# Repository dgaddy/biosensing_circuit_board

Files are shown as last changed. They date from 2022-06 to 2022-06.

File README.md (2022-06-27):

These designs are for a low-cost biosensing board for measuring signals such as EMG, EEG, or ECG.

The board is designed to plug into an Adafruit Feather M4 Express and send the collected signals back to a computer over USB.

**Disclaimer:** Connecting electrical circuitry to your body can be dangerous.  I do not make any guarantees to the safety of this design.  Before building, you should conduct your own analysis of safety.

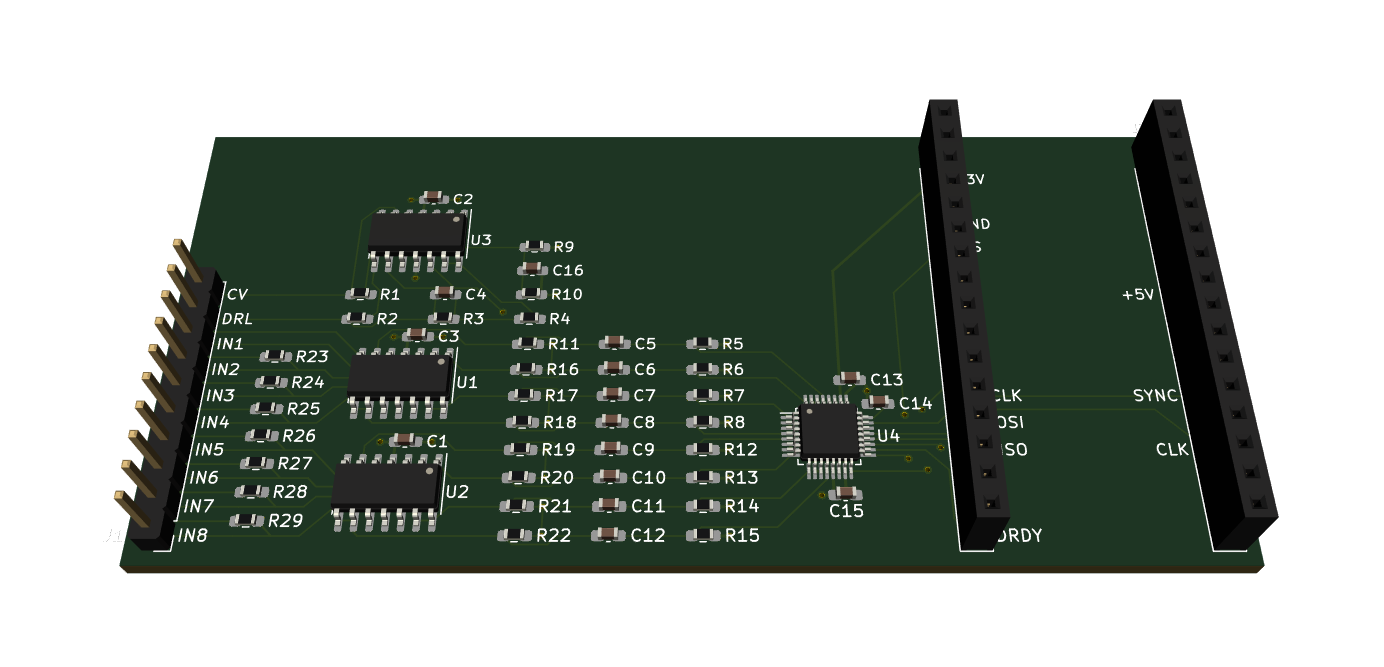
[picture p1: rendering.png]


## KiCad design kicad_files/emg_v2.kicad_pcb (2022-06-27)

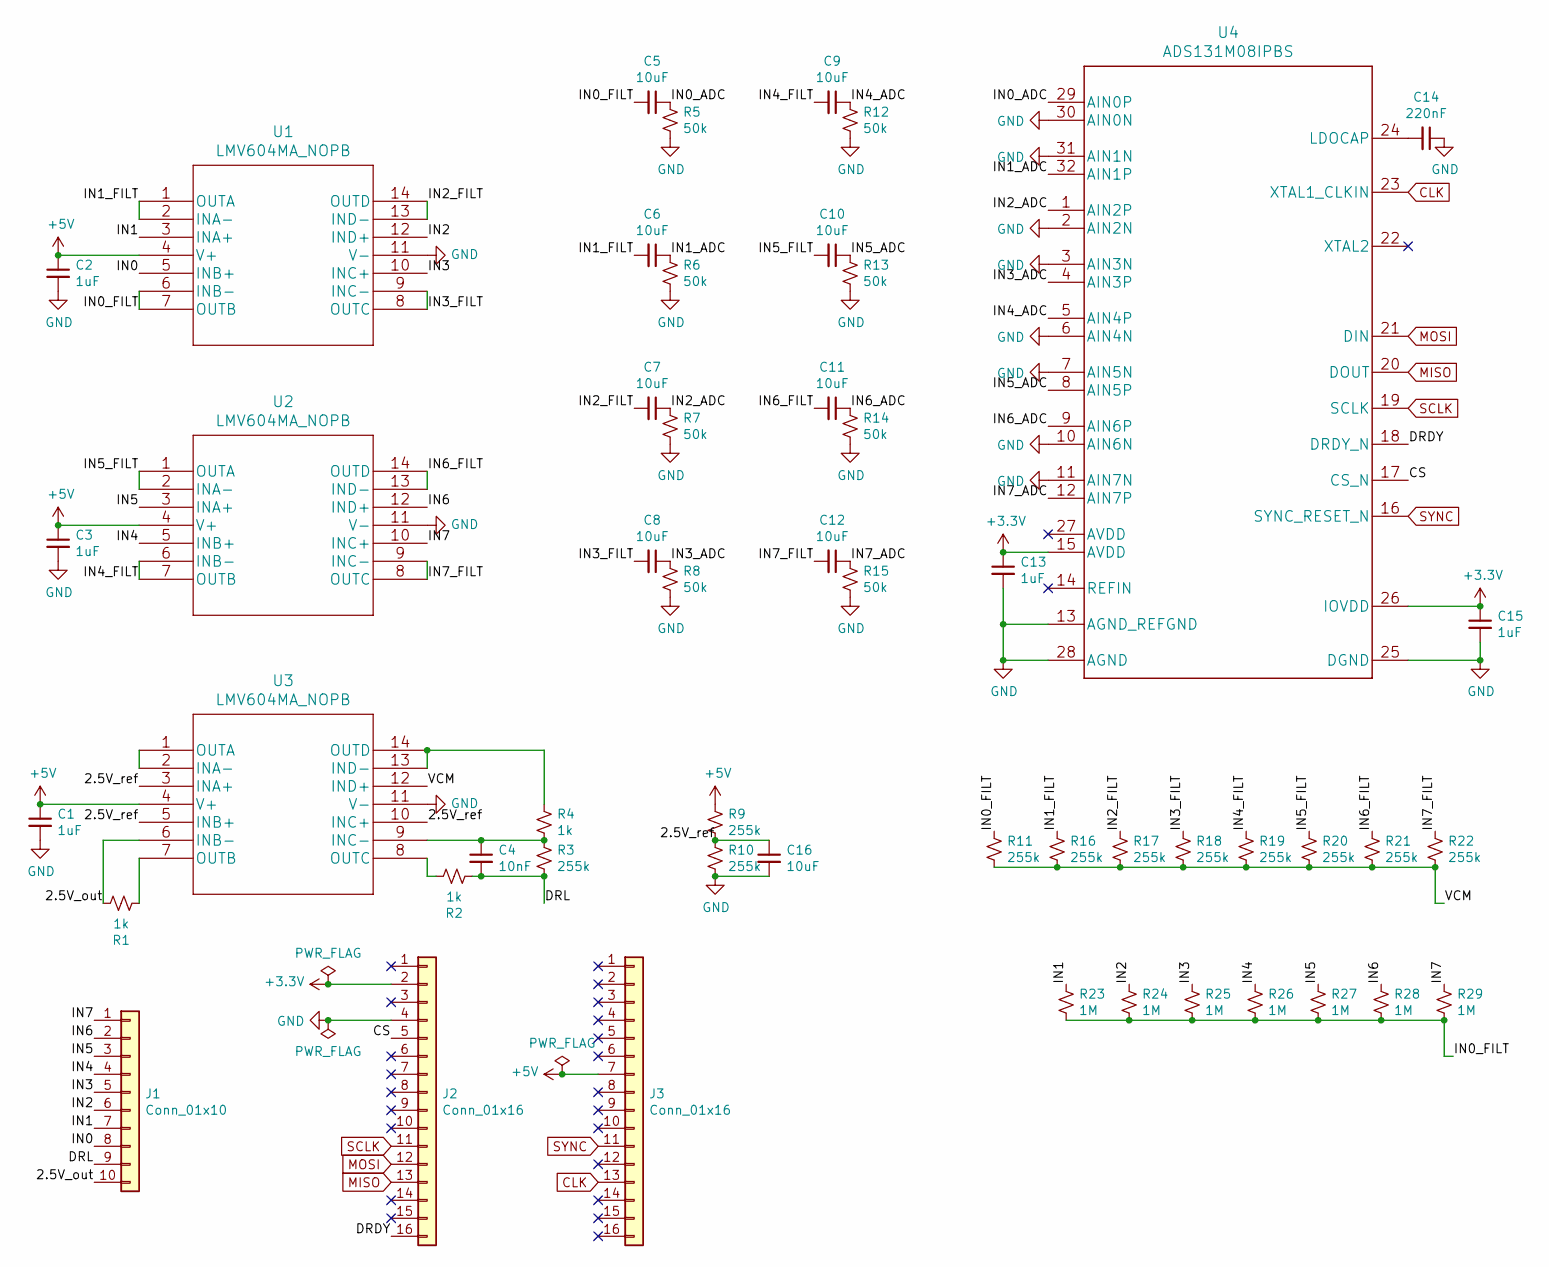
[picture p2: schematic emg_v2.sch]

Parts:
C1, C2, C3, C13, C15: 1uF; C_0603_1608Metric_Pad1.08x0.95mm_HandSolder
C4: 10nF; C_0603_1608Metric_Pad1.08x0.95mm_HandSolder
C5, C6, C7, C8, C9, C10, C11, C12, C16: 10uF; C_0603_1608Metric_Pad1.08x0.95mm_HandSolder
C14: 220nF; C_0603_1608Metric_Pad1.08x0.95mm_HandSolder
J1: Conn_01x10; PinHeader_1x10_P2.54mm_Vertical
J2, J3: Conn_01x16; PinSocket_1x16_P2.54mm_Vertical
R1, R2, R4: 1k; R_0603_1608Metric_Pad0.98x0.95mm_HandSolder
R3, R9, R10, R11, R16, R17, R18, R19, R20, R21, R22: 255k; R_0603_1608Metric_Pad0.98x0.95mm_HandSolder
R5, R6, R7, R8, R12, R13, R14, R15: 50k; R_0603_1608Metric_Pad0.98x0.95mm_HandSolder
R23, R24, R25, R26, R27, R28, R29: 1M; R_0603_1608Metric_Pad0.98x0.95mm_HandSolder
U1, U2, U3: LMV604MA_NOPB; SOIC-14_3.9x8.7mm_P1.27mm
U4: ADS131M08IPBS; LQFP-32_5x5mm_P0.5mm

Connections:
+3V3: C13.1, C15.1, J2.2, U4.15 (AVDD), U4.26 (IOVDD)
+5V: C1.1, C2.1, C3.1, J3.7, R9.1, U1.4 (V+), U2.4 (V+), U3.4 (V+)
/2.5V_out: J1.10, R1.1, U3.6 (INB-)
/2.5V_ref: C16.1, R9.2, R10.1, U3.3 (INA+), U3.5 (INB+), U3.10 (INC+)
/CS: J2.5, U4.17 (CS_N)
/DRDY: J2.16, U4.18 (DRDY_N)
/DRL: C4.2, J1.9, R2.2, R3.2
/IN0: J1.8, U1.5 (INB+)
/IN0_ADC: C5.1, R5.1, U4.29 (AIN0P)
/IN0_FILT: C5.2, R11.1, R23.2, R24.2, R25.2, R26.2, R27.2, R28.2, R29.2, U1.6 (INB-), U1.7 (OUTB)
/IN1: J1.7, R23.1, U1.3 (INA+)
/IN1_ADC: C6.1, R6.1, U4.32 (AIN1P)
/IN1_FILT: C6.2, R16.1, U1.1 (OUTA), U1.2 (INA-)
/IN2: J1.6, R24.1, U1.12 (IND+)
/IN2_ADC: C7.1, R7.1, U4.1 (AIN2P)
/IN2_FILT: C7.2, R17.1, U1.13 (IND-), U1.14 (OUTD)
/IN3: J1.5, R25.1, U1.10 (INC+)
/IN3_ADC: C8.1, R8.1, U4.4 (AIN3P)
/IN3_FILT: C8.2, R18.1, U1.8 (OUTC), U1.9 (INC-)
/IN4: J1.4, R26.1, U2.5 (INB+)
/IN4_ADC: C9.1, R12.1, U4.5 (AIN4P)
/IN4_FILT: C9.2, R19.1, U2.6 (INB-), U2.7 (OUTB)
/IN5: J1.3, R27.1, U2.3 (INA+)
/IN5_ADC: C10.1, R13.1, U4.8 (AIN5P)
/IN5_FILT: C10.2, R20.1, U2.1 (OUTA), U2.2 (INA-)
/IN6: J1.2, R28.1, U2.12 (IND+)
/IN6_ADC: C11.1, R14.1, U4.9 (AIN6P)
/IN6_FILT: C11.2, R21.1, U2.13 (IND-), U2.14 (OUTD)
/IN7: J1.1, R29.1, U2.10 (INC+)
/IN7_ADC: C12.1, R15.1, U4.12 (AIN7P)
/IN7_FILT: C12.2, R22.1, U2.8 (OUTC), U2.9 (INC-)
/VCM: R11.2, R16.2, R17.2, R18.2, R19.2, R20.2, R21.2, R22.2, U3.12 (IND+)
CLK: J3.13, U4.23 (XTAL1_CLKIN)
GND: C1.2, C2.2, C3.2, C13.2, C14.1, C15.2, C16.2, J2.4, R5.2, R6.2, R7.2, R8.2, R10.2, R12.2, R13.2, R14.2, R15.2, U1.11 (V-), U2.11 (V-), U3.11 (V-), U4.2 (AIN2N), U4.3 (AIN3N), U4.6 (AIN4N), U4.7 (AIN5N), U4.10 (AIN6N), U4.11 (AIN7N), U4.13 (AGND_REFGND), U4.25 (DGND), U4.28 (AGND), U4.30 (AIN0N), U4.31 (AIN1N)
MISO: J2.13, U4.20 (DOUT)
MOSI: J2.12, U4.21 (DIN)
unnamed: C4.1, R3.1, R4.2, U3.9 (INC-)
unnamed: C14.2, U4.24 (LDOCAP)
unnamed: R1.2, U3.7 (OUTB)
unnamed: R2.1, U3.8 (OUTC)
unnamed: R4.1, U3.13 (IND-), U3.14 (OUTD)
unnamed: U3.1 (OUTA), U3.2 (INA-)
SCLK: J2.11, U4.19 (SCLK)
SYNC: J3.11, U4.16 (SYNC_RESET_N)

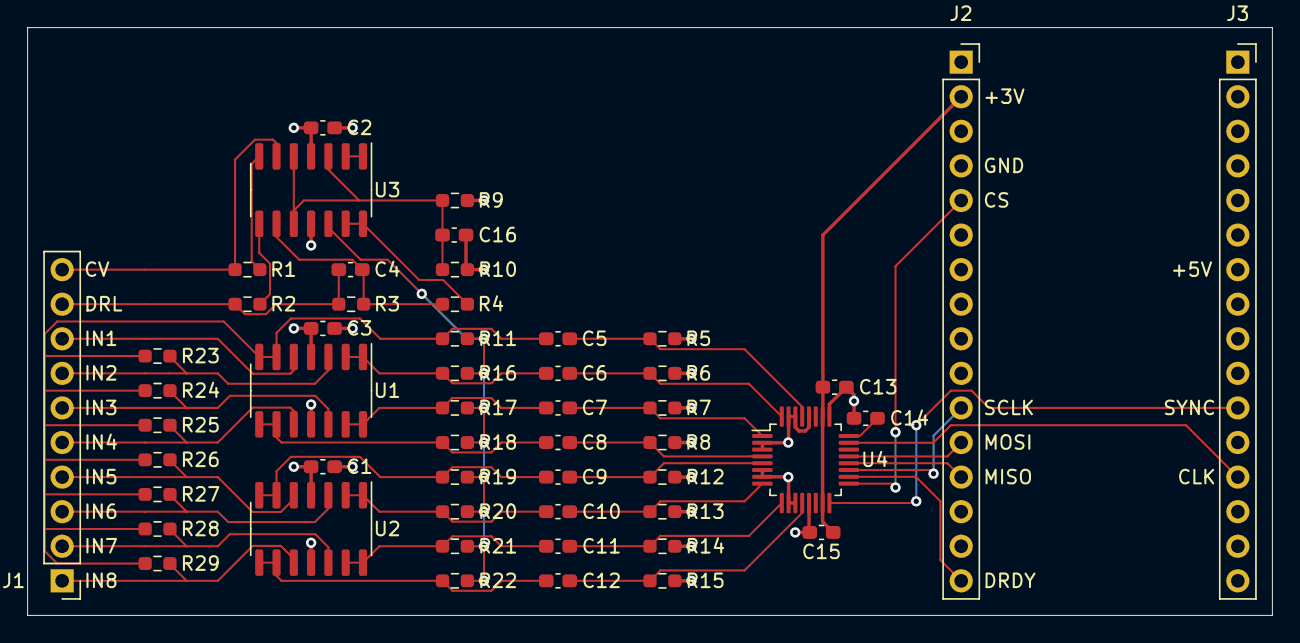
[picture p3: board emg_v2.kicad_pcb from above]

Board: 4 copper layers, 91.4 x 43.2 mm, 52 parts (0 on the bottom side), 44 nets.

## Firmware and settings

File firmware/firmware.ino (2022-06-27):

#include <SPI.h>
#include "clock.h"

#define LED 13
#define DRDY 4
#define SYNC 10
// clock on pin 6

#define N_ADC 1
const int cs_pins[N_ADC] = {A0};

#define N_INACTIVE_ADC 0
const int inactive_cs_pins[N_INACTIVE_ADC] = {};

unsigned long sample_time = 0;

void setup() {
  pinMode(DRDY, INPUT);
  pinMode(LED, OUTPUT);
  pinMode(SYNC, OUTPUT);

  digitalWrite(SYNC, HIGH);

  for (int i = 0; i < N_ADC; i++) {
    pinMode(cs_pins[i], OUTPUT);
    digitalWrite(cs_pins[i], HIGH);
  }

  for (int i = 0; i < N_INACTIVE_ADC; i++) {
    pinMode(inactive_cs_pins[i], OUTPUT);
    digitalWrite(inactive_cs_pins[i], HIGH);
  }

  delayMicroseconds(1);
  clockSetup();

  SPI.begin();
  
  SPI.beginTransaction(SPISettings(4000000, MSBFIRST, SPI_MODE1));

  delay(1);

  while (Serial.read() != 'S') ;
  Serial.write(0xFA);
  digitalWrite(LED, HIGH);

  for (int i = 0; i < N_ADC; i++) {
    writeConfigRegisters(cs_pins[i]);
  }

  digitalWrite(SYNC, LOW);
  delayMicroseconds(10); // must be less than 2048*adc_clck
  digitalWrite(SYNC, HIGH);

  sample_time = micros();
}

void loop() {
  unsigned long t = micros();
  if(digitalRead(DRDY) == LOW) {
    // data is ready
    
    Serial.write("s"); // start of data
    
    unsigned long d = t - sample_time;
    sample_time = t;
    
    byte time_data[4] = {d>>24,(d>>16)%256,(d>>8)%256,d%256};
    Serial.write(time_data, 4);

    for (int i = 0; i < N_ADC; i++) {
      readData(cs_pins[i]);
      delayMicroseconds(1);
    }
  }
  delayMicroseconds(1);
}

void clear(byte *data, int len) {
  for (int i = 0; i < len; i++) {
    data[i] = 0;
  }
}

void transfer(int cs_pin, byte *data, int len) {
  digitalWrite(cs_pin, LOW);
  delayMicroseconds(1);
  SPI.transfer(data, len);
  delayMicroseconds(1);
  digitalWrite(cs_pin, HIGH);
}

// typical frame is 10 words, 3 bytes per word

void printRegisters(int cs_pin) {
  byte data[30]; // 1 whole frame to send command, response comes on next frame
  clear(data, 30);
  data[0] = 0b10100000;
  data[1] = 8; // read 9 registers
  transfer(cs_pin, data, 30);

  // data out: ack + 9 reg (+ crc, but we are ignoring)
  clear(data, 30);
  transfer(cs_pin, data, 30);

  Serial.println("registers:");
  for (int i = 0; i < 9; i++) {
    Serial.print(i, HEX);
    Serial.print(": ");
    Serial.print(data[3*i+3], HEX);
    Serial.print(" ");
    Serial.println(data[3*i+4], HEX);
  }
}

void writeConfigRegisters(int cs_pin) {
  byte data[30] = {
    0x61, 0x06, 0x00, // write command, reg 2-8
    0x05, 0x10, 0x00, // mode
    0xff, 0x16, 0x00, // clock (enable all channels, oversample 4096) - first byte 01 for single channel
    0x44, 0x44, 0x00, // gain1 (all channels gain 16)
    0x44, 0x44, 0x00, // gain2 (all channels gain 16)
    0x06, 0x00, 0x00, // cfg
    0x00, 0x00, 0x00, // threshold msb
    0x00, 0x00, 0x00, // threshold lsb
    0x00, 0x00, 0x00, // pad
  };
  transfer(cs_pin, data, 30);
}

void readData(int cs_pin) {
  byte data[30];
  clear(data, 30);
  transfer(cs_pin, data, 30);
  //response is: prev command response, 8 channels data, crc

  Serial.write(data+3, 8*3);
}

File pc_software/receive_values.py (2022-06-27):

import serial
import time
import numpy as np
import scipy.signal
import multiprocessing
import queue

import matplotlib.pyplot as plt
from matplotlib.animation import FuncAnimation

n_channels = 8

class IncrementalDataFilter(object):
    def __init__(self, n_channels, max_len, sample_frequency):
        self.max_len = max_len
        self.sample_frequency = sample_frequency

        self.notch_zi = [np.zeros([2, n_channels]) for _ in range(60, int(sample_frequency/2), 60)]
        self.notch_zi_2 = [np.zeros([2, n_channels]) for _ in range(60, int(sample_frequency/2), 60)]
        self.highpass_zi = np.zeros([3, n_channels])

        self.processed_signals = np.zeros([max_len, n_channels])
        self.raw_processed_signals = np.zeros([max_len, n_channels])
        self.new_samples = []

        self.t_values = [0] * max_len

    def add_sample(self, sample, t_value=None):
        self.new_samples.append(sample)
        if t_value is not None:
            self.t_values.append(t_value)

    def get_signals(self):
        if len(self.new_samples) > 0:
            new_signals = np.array(self.new_samples)

            self.raw_processed_signals = np.concatenate([self.raw_processed_signals, new_signals], axis=0)[-self.max_len:,:]

            for i, freq in enumerate(range(60, int(self.sample_frequency/2), 60)):
                b, a = scipy.signal.iirnotch(freq, 10, self.sample_frequency)
                new_signals, self.notch_zi[i] = scipy.signal.lfilter(b, a, new_signals, axis=0, zi=self.notch_zi[i])
                new_signals, self.notch_zi_2[i] = scipy.signal.lfilter(b, a, new_signals, axis=0, zi=self.notch_zi_2[i])

            b, a = scipy.signal.butter(3, 10, 'highpass', fs=self.sample_frequency)
            new_signals, self.highpass_zi = scipy.signal.lfilter(b, a, new_signals, axis=0, zi=self.highpass_zi)

            self.processed_signals = np.concatenate([self.processed_signals, new_signals], axis=0)[-self.max_len:,:]

            self.new_samples = []

        return self.processed_signals, self.raw_processed_signals

    def get_t_values(self):
        self.t_values = self.t_values[-self.max_len:]
        return np.array(self.t_values)


class DataStream(object):
    def __init__(self):
        self.serial = serial.Serial('/dev/ttyACM0', baudrate=1000000, timeout=5)
        self.next_char = None

    def start(self):
        self.serial.reset_input_buffer()
        self.serial.write(b'S')
        while self.serial.read() != b'\xFA':
            time.sleep(0.1)
            self.serial.reset_input_buffer()
            self.serial.write(b'S')

    def stop(self):
        self.serial.write(b'E')

    def close(self):
        self.serial.flush()
        self.serial.close()

    def has_values(self):
        return self.serial.in_waiting >= 2

    def get_value(self):
        skip_count = 0
        while self.serial.read() != b's':
            skip_count += 1
        if skip_count > 0:
            print(f'skipped {skip_count} bytes')
        in_bytes = self.serial.read(4+n_channels*3)
        t = (in_bytes[0]<<24)+(in_bytes[1]<<16)+(in_bytes[2]<<8)+in_bytes[3]

        values = []
        for i in range(n_channels):
            v = (in_bytes[3*i+4]<<16)+(in_bytes[3*i+5]<<8)+in_bytes[3*i+6]

            if v >= 0x800000:
                v -= 0x1000000

            v = v * 1.2 * 1000000 / 2**23 / 16 # note: will need to adjust with gain change
            values.append(v)

        return values, t

class Display(object):
    def __init__(self, data_buffer):
        t = 5000

        plt.ion()
        fig, axis = plt.subplots(1)
        axis.axis((0,t,-1000,1000*n_channels))
        lines = axis.plot(np.zeros((t,n_channels)))
        for l,c in zip(lines, ['grey', 'mediumpurple', 'blue', 'green', 'yellow', 'orange', 'red', 'sienna']):
            l.set_color(c)
        text = axis.text(50,50,'')

        fig.tight_layout(pad=0)
        plt.show()

        def update_plot(frame):
            """ This is called by matplotlib for each plot update. """
            data, raw_data = data_buffer.get_signals()

            raw_mean = np.abs(raw_data.mean(axis=0)).max()
            raw_rms = raw_data.std(axis=0).max()

            data = data - data[:,0,np.newaxis]

            for i in range(0, n_channels):
                lines[i].set_ydata(data[:,i] + 1000*i)

            rms = data.std(axis=0).max()
            text.set_text(f'RMS: {rms:.2f} offset: {raw_mean:.2f} raw RMS: {raw_rms:.2f}')
            return lines

        self.ani = FuncAnimation(fig, update_plot, interval=30)

    def update(self):
        plt.gcf().canvas.draw_idle()
        plt.gcf().canvas.start_event_loop(0.005)


def serial_thread(queue):
    stream = DataStream()
    stream.start()
    print('started')

    try:
        while True:
            v, t = stream.get_value()
            queue.put((v, t), block=False)

    finally:
        #XXX doesn't gracefully stop on ctrl-c
        print('stopping')
        stream.stop()
        stream.close()

if __name__ == '__main__':
    q = multiprocessing.Queue()
    st = multiprocessing.Process(target=serial_thread, args=(q,))
    st.daemon = True
    st.start()

    values = []
    times = []
    display_buffer = IncrementalDataFilter(n_channels, 5000, 976.6)

    display = Display(display_buffer)
    while True:
        display.update()
        while not q.empty():
            v, t = q.get()

            values.append(v)
            times.append(t)
            display_buffer.add_sample(v, t)

            if t < 900:
                print('short time between samples')
            if t > 1030:
                print('time gap', t)

            if len(times) > 50000:
                # TODO: do this better
                times.clear()
                values.clear()
